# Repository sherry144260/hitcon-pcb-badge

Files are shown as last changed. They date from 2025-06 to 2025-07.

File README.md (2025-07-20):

# HITCON PCB Badge

## Firmware Development

execute `fw/merge.py` to merge STM32CubeIDE generated `main.c` with user code in `main.cc` into `main.cc`.

### Choose your hardware

In STM32CubeIDE, go to **Project > Build Configurations > Set Active > V1.1 / V2.0 / V2.1** to switch between hardware versions.  
Also go to **Run > Run Configurations > C/C++ Application** and choose the correct Build Configuration
There are different firmware versions for each hardware revision.  
To identify your hardware version, check the back of your badge.
- V1.1 (2024 CMT Attendee)
- V2.0 (2025 first prototype)
- V2.1 (2025 CMT Attendee)

## Timers and DMA Channels

- [x] IR Tx: PWM Output from TIM3_CH3, Output PB0, DMA1 Ch2
  - Compare: 63/4 = 16
  - Mode: Circular Normal Peripheral to Memory

| | Peripheral | Memory |
| --- | --- | --- |
| Increment Address | X | V |
| Data Width | Half Word  | Half Word |

- [x] IR Rx: DMA Triggered through TIM2_CH3, Input PA0 read by DMA1 Ch1
  - Compare: 105
  - Mode: Circular Peripheral to Memory

| | Peripheral | Memory |
| --- | --- | --- |
| Increment Address | X | V |
| Data Width | Half Word  | Half Word |

- [x] Led Rows/Cols: DMA Triggered through TIM1_UP, Output PB6-9(Rows), Output PB1-2/10-15(Cols), written by DMA1 Ch5
  - Mode: Circular Memory to Peripheral

| | Peripheral | Memory |
| --- | --- | --- |
| Increment Address | X | V |
| Data Width | Word | Word |

- [x] Led Brightness control: PWM Output from TIM3_CH2
- [x] Buttons: Reads Input PA4-10, PA15 through TIM4_CH2, DMA1 Ch4
  - Compare: 5
  - Mode: Circular Peripheral to Memory

| | Peripheral | Memory |
| --- | --- | --- |
| Increment Address | X | V |
| Data Width | Half Word  | Half Word |

- [x] Cross-board communication TX: USART2 TX, DMA1 Ch7
- [x] Cross-board communication RX: USART2 RX, DMA1 Ch6

- [x] TIM4: Operates at 100Hz for Button
  - Prescaler: 12000-1
  - Counter Period: 10-1
- [x] TIM3: Operates at 38kHz for PWM out.
  - Prescaler: 5-1
  - Counter Period: 63-1
  - Master Mode Enable
- [x] TIM2:
  - Prescaler: 0
  - Counter Period: 4-1
  - Slave Mode: External Clock
  - Trigger Source: ITR2 (TIM3 Update Event)
  - Operates at 1/4 speed of TIM3, synchronization needed for IR pulse alignment and brightness adjustment.
  - Also operates at 1/4 bit time for capturing IR.
  - TIM2 = 38/4 kHz = 9.5kHz.
  - Bit time = 4/9.5kHz = 421us (each bit is 16 pulse).
- [x] TIM1:
  - Prescaler: 5-1
  - Counter Period: 1500-1
  - LED refreshes at 3200/16 = 200Hz.

## Format

To check format, please install `clang-format` first.

```sh
# under hitcon-pcb-badge
./lint.sh # check format
./lint.sh -i # auto format
```

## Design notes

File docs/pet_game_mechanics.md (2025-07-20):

# 設備條件
畫面 8x16 
LED燈藍色和紅色，一台只有一種顏色

# 遊戲機制

- 第一次進入遊戲，可以選擇要孵狗蛋還是貓蛋
- 選擇後開始計搖晃次數，顯示孵蛋進度條（計次300下後孵蛋成功）
    - Global 晃動次數。
- 若孵蛋成功，再次進入遊戲畫面時即可看到你的寵物
    - Optional: 孵蛋成功小動畫（Justin 要畫嗎)
        > Yee (ok)
- 寵物有「生命值」、「等級」、「飽食度」三個數值
    - 生命值：三顆心，生命值歸零寵物進入虛弱狀態
        - aka, 能輸幾次
    - 飽食度：全滿為4，每1小時扣1飽食度，若飽食度歸零寵物進入虛弱畫面
    - 等級：初始為1，每計次100下等級+1 **(越來越難，算式待訂)**
-  可做行動
    - 訓練：NBA Shot meter練習器，若5次全中增加1等
        - 進度條 QTE
    - 餵食：可愛動畫，增加一格飽實度，畫面顯示你是一個好駭客
    - 戰鬥
        - 雙方進入戰鬥畫面，對接後顯示「Are you ready?」 任何一方按確認後進入戰鬥畫面
            > too many words, changed to icon - Yee (ok)
        - 戰鬥方式：NBA shot meter (Aoaa 看得懂)
            - 對戰方式：
                - Hitbox 每次隨機出現，下方指示物會來回走一次，玩家需要在下方指示物對準Hitbox時按下確認鍵，才算成功。
                - 指示物來回走一次以後會改變hitbox位子
                - 此過程進行5次後計分
            - 對戰後計算
                - 攻擊力(等級) X 成功次數的平方，兩個數字比大小，贏者勝 
                    - 一局比大小結束
                - 若成功次數為5次，有1%機率引發直接讓對方進入虛弱狀態的爆擊
                - 贏的一方補一顆心，輸的一方減少一顆心
- 小駭客中心(寶可夢中心)：Badge與寶可夢中心對接，補滿三顆心和飽食度
- 若寵物進入虛弱狀態，降一等，並無法進行任何活動，需要到寶可夢中心回滿血後才可繼續遊戲

# 遊戲功能階層

(孵蛋前)
- 小駭客
    - 畫面顯示選擇狗狗 OR 貓貓，選擇後進入孵蛋進度條

(孵蛋後)
- 小駭客
    - 寵物畫面（希望可以是動畫）
        - 狀態顯示
            - 血條
            - 等級/等級條
            - 飽實度
        - 訓練
        - 餵食
        - 戰鬥

# 畫面需求 for Justin
1. 蛋
2. 孵蛋成功小動畫
3. 狗&貓 (8x16的版面都可以用，希望可以動)
4. 貓虛弱畫面/狗虛弱畫面
5. 寶可夢中心 (愛心跑馬燈之類的)

---

### 跨版對戰相關

> 註：畫面不用額外刻

1. tama APP pet idle 狀態下，偵測板子是否對插 
    * 參考畫面 截圖 2025-07-06 下午6.23.48
2. 確認對插，跳出戰鬥確認頁面 
    * 截圖 2025-07-06 下午6.24.52

3. 雙方確認戰鬥，==交換寵物種類==。(按退出則回 tama app pet idle) 
4. 進入戰鬥對峙互看頁面
    * 截圖 2025-07-06 下午6.25.25
5. 畫面 delay 幾秒後跳出 "Battle start" page
6. "Battle start" page 過幾秒內進入 QTE game page
7. 進行五次 QTE，統計成功次數(需計時 timeout)
8. 完成QTE的，等待

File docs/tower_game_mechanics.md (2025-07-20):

# 設備數量
15-20個基地台
基地台和Badge可雙向溝通
基地台可傳輸距離約5-10公尺

# 遊戲機制

## 遊戲機制簡介
1. 一開始所有都是中立塔台，中立塔台需要分數達到一定程度才會被佔領
    - 塔台數值：設定分數下限 & 上限，中間有一區間會判定為中立塔台。EX: -1000 ~ 1000, 中間-300~300為中立值
3. 會眾透過遊戲、互動取得分數，分數會立即被使用到攻擊／防禦附近的塔台 
4. 塔台數值會隨時間下降，因此已經被佔領的塔台，若有一段時間都沒有人去加減分數，會回到中立塔台
5. 佔領塔數較多的該隊獲勝

待確認：
1. 有鑽漏洞（讓會眾玩Hacking）的機制嗎
2. 可以當內鬼?

## 分數類別 & 分數使用機制

### 分數類別
~~- 可使用分數：玩任一遊戲，還可以支配的分數~~
- 已使用分數

### 分數使用機制 

#### 獲得當下立刻使用
* 人潮明顯，好拍照，但會怕把議程空間擠爆
* 不需要額外有一個數值儲存已取得的分數

## 取得分數的方法
注意：這邊所有的分數定義都是先以會眾角度為考量，因此先不考慮藍隊實際上是+10/ 紅隊實際上計分是-10這個問題
* 站在塔台旁邊搖晃Badge
    * 一般塔台
        *  10秒內搖晃次數超過20次 +10分
            * 設定原因：希望是有意識的搖晃再計分，不要單純走路就計分
        * 每5秒多+1分
        * EX 連續搖晃20秒時，會變成10+11分。搖晃30秒時，會變成10+11+12。搖晃越久分數增加越多
    * 贊助商塔台
        * 10秒內搖晃次數超過20次 +20分
        * 每5秒多+2分
        * EX 連續搖晃20秒時，會變成20+21分。
* 小遊戲：
    * Dino
        * 每5秒計2分
        * 每5秒多+1分
        * EX: 成功跑15秒，分數為2+3+4
    * Snake
        + Snake score 每5分計1分
        + 每5分多+1分
        + 單機模式，EX: 若Snake score結果顯示為35，分數為= 1+2+3+4+5+6+7
        + 對戰模式：勝利的一方獲得2倍的分數，輸的一方獲得一倍的分數
        (給石頭：分數後端算。勝利與否只看分數高低。即便貪食蛇有人先撞牆，還是分數高的贏。若平分的話就是送一樣的分數)
    * Tetris
        * Tetris Score 每15分計1分
        * 每15分多+1分
        * 單機模式，EX: 若Tetris score結果顯示為150，1+2+3+4+5+6+7+8+9+10
        * 對戰模式：勝利的一方獲得2倍的分數，輸的一方獲得一倍的分數
        (給石頭：分數後端算。勝利與否只看分數高低。即便貪食蛇有人先撞牆輸了。若平分的話就是送一樣的分數)
* 贊助商活動
    * 贊助商放特殊基地台，在贊助商旁邊搖晃Badge的話可獲得更多分數
        * 10秒內搖晃次數超過20次 +20分
        * 每5秒多+2分
        * EX 連續搖晃20秒時，會變成20+21分。
    * 贊助商有特殊Badge 
        * 跟贊助商對接Badge，駭客寵物可升一等，一個贊助商只能讓寵物升等一次 (重複對接不能重複升等)
        * 若跟所有贊助商都對接過一次，隨即攻擊/防禦附近的塔台300分
       
* ReCTF：解題可以獲得分數倍率
    * 預設題目有24題
    * CTFd 登入 官網 SSO Token 後，可以在 Profile 頁面綁定 Badge。(活動前edward會事先提供一個解多少題的清單)
    * 每解一題可以增加0.04的分數倍率，EX: 倍率為1.04、1.08、1.12、1.16.....，全部解完的分數倍率為兩倍(先成上去後小數點四捨五入)

## 遊戲結算
* 團隊：佔領塔數較多的那隊獲勝（獎品待確認）
* 個人：已使用分數最高者獲勝

設定獲勝條件

## 記分板
* 個人已經輸出過的分數
* 地圖：各地佔領情況，分數差異

archieve
胎死腹中的想法
~~有沒有台主~~

分數儲存後使用 (建議)
說明：獲得分數後儲存起來，之後再決定要將分數加到哪個塔台
* 人流不會都擠在基地台旁邊（畢竟基地台可能會放在議程空間裡面）
* 在何時何地都可以參與遊戲，可以回家繼續玩小遊戲累積分數

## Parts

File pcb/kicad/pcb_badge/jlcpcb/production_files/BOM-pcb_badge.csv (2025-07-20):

Comment | Designator | Footprint | LCSC
0.1u | C1,C21,C30,C31,C32,C33,C40,C50,C51,C80 | C_0402_1005Metric_Pad0.74x0.62mm_HandSolder | C1525
1u | C10,C11 | C_0603_1608Metric_Pad1.08x0.95mm_HandSolder | C152900
20p | C37,C38 | C_0402_1005Metric_Pad0.74x0.62mm_HandSolder | C1554
4.7u | C60 | C_0603_1608Metric_Pad1.08x0.95mm_HandSolder | C1705
10M | R11,R4 | R_0402_1005Metric_Pad0.72x0.64mm_HandSolder | C177265
TLV70328DBVR | U1 | SOT-23-5 | C19631758
10u | C20,C22,C23,C24,C25,C26,C92 | C_0603_1608Metric_Pad1.08x0.95mm_HandSolder | C19702
20R | R1,R2 | R_0402_1005Metric_Pad0.72x0.64mm_HandSolder | C203133
QX2304L33F | U2 | SOT-23-5 | C219039
100 | R61 | R_0402_1005Metric_Pad0.72x0.64mm_HandSolder | C25076
220 | R14 | R_0402_1005Metric_Pad0.72x0.64mm_HandSolder | C25091
300 | R90,R91,R92,R93,R94,R95,R96,R97 | R_0402_1005Metric_Pad0.72x0.64mm_HandSolder | C25102
470 | R21,R31,R32,R33,R34,R8,R9 | R_0402_1005Metric_Pad0.72x0.64mm_HandSolder | C25117
SW_MEC_5E | SW1,SW2,SW3,SW4,SW5,SW6,SW7,SW8 | SOIC4_TL3301SPF160RGTAPE_EWI | C255812
100k | R16,R17,R18,R19,R5,R6,R7 | R_0402_1005Metric_Pad0.72x0.64mm_HandSolder | C25741
4.7k | R20,R3,R50,R51 | R_0402_1005Metric_Pad0.72x0.64mm_HandSolder | C25900
5.1k | R24,R25 | R_0402_1005Metric_Pad0.72x0.64mm_HandSolder | C25905
CYL104R-33UH | L20 | L_10.4x10.4_H4.8 | C2879699
Conn_01x03_Pin | J5 | PinHeader_1x03_P2.54mm_Vertical | C2897385
DEALON USB-TYPE-C-018 | J1 | DEALON USB-TYPE-C-018 | C2927038
110R | R164 | R_1206_3216Metric_Pad1.30x1.75mm_HandSolder | C2934192
SOD4007-MS | D18,D2 | D_SOD-123F | C3008061
TAXM8M4RFDCET2T | Y1 | Oscillator_SMD_Abracon_ASE-4Pin_3.2x2.5mm | C403948
SI2302 | Q1 | SOT-23 | C4748714
2N7002 | Q9,Q90,Q91,Q910,Q911,Q912,Q913,Q914,Q915,Q92,Q93,Q94,Q95,Q96,Q97,Q98,Q99 | SOT-23 | C4748728
NSR0320MW2T1G | D9 | D_SOD-323_HandSoldering | C48192
Conn_01x03_Pin | J4 | PinHeader_1x03_P2.54mm_Vertical | C5383096
0 | R10,R23 | R_0402_1005Metric_Pad0.72x0.64mm_HandSolder | C60485
NEWOPTO XYC-IRA2835A90-X4 | D161 | LED_PLCC_2835_Handsoldering | C6081290
74HC238 | U4,U8 | SOP-16_3.9x9.9mm_P1.27mm | C7432189
STM32F103CBT6 | U3 | LQFP-48_7x7mm_P0.5mm | C8304
IRM-H638T/TR2 | U6 | IRM-H638T | C91447
JSM2301S | Q2 | SOT-23 | C916399
BAT_2 | BT1 | BH-AAA-B5AK001 | C964881
LED | D00,D01,D02,D03,D04,D05,D06,D07,D10,D100,D101,D102,D103,D104,D105,D106,D107,D11,D110,D111,D112,D113,D114,D115,D116,D117,D12,D120,D121,D122,D123,D124,D125,D126,D127,D13,D130,D131,D132,D133,D134,D135,D136,D137,D14,D140,D141,D142,D143,D144,D145,D146,D147,D15,D150,D151,D152,D153,D154,D155,D156,D157,D16,D17,D20,D21,D22,D23,D24,D25,D26,D27,D30,D31,D32,D33,D34,D35,D36,D37,D40,D41,D42,D43,D44,D45,D46,D47,D50,D51,D52,D53,D54,D55,D56,D57,D60,D61,D62,D63,D64,D65,D66,D67,D70,D71,D72,D73,D74,D75,D76,D77,D80,D81,D82,D83,D84,D85,D86,D87,D90,D91,D92,D93,D94,D95,D96,D97 | LED_0402_1005Metric_Pad0.77x0.64mm_HandSolder | C965790
LSM6DS3TR-C | U5 | QFN_S3TR-C_STM | C967633
NC | D160 | LED_PLCC_2835_Handsoldering
Conn_01x02_Pin | J7 | PinHeader_1x02_P2.54mm_Vertical
NC | D3 | LED_0603_1608Metric_Pad1.05x0.95mm_HandSolder
Conn_01x04_Pin | J3 | PinHeader_1x04_P2.54mm_Vertical
NC | R29 | R_0402_1005Metric_Pad0.72x0.64mm_HandSolder
NC | R36 | R_0402_1005Metric_Pad0.72x0.64mm_HandSolder
NC | R35 | R_0402_1005Metric_Pad0.72x0.64mm_HandSolder
NC | C34 | C_0402_1005Metric_Pad0.74x0.62mm_HandSolder
NC | R22 | R_0402_1005Metric_Pad0.72x0.64mm_HandSolder
NC | D1 | D_SOD-323_HandSoldering
NC | R30 | R_0402_1005Metric_Pad0.72x0.64mm_HandSolder
NC | D164 | LED_PLCC_2835_Handsoldering
NC | D166 | LED_PLCC_2835_Handsoldering
Conn_01x02_Pin | J2 | JWT_A3963_1x02_P3.96mm_Vertical
NC | D163 | LED_PLCC_2835_Handsoldering
NC | D167 | LED_PLCC_2835_Handsoldering
NC | D162 | LED_PLCC_2835_Handsoldering
NC | D165 | LED_PLCC_2835_Handsoldering
NC | R165 | R_1206_3216Metric_Pad1.30x1.75mm_HandSolder
NC | R166 | R_1206_3216Metric_Pad1.30x1.75mm_HandSolder
NC | R162 | R_1206_3216Metric_Pad1.30x1.75mm_HandSolder
NC | R167 | R_1206_3216Metric_Pad1.30x1.75mm_HandSolder
NC | R163 | R_1206_3216Metric_Pad1.30x1.75mm_HandSolder

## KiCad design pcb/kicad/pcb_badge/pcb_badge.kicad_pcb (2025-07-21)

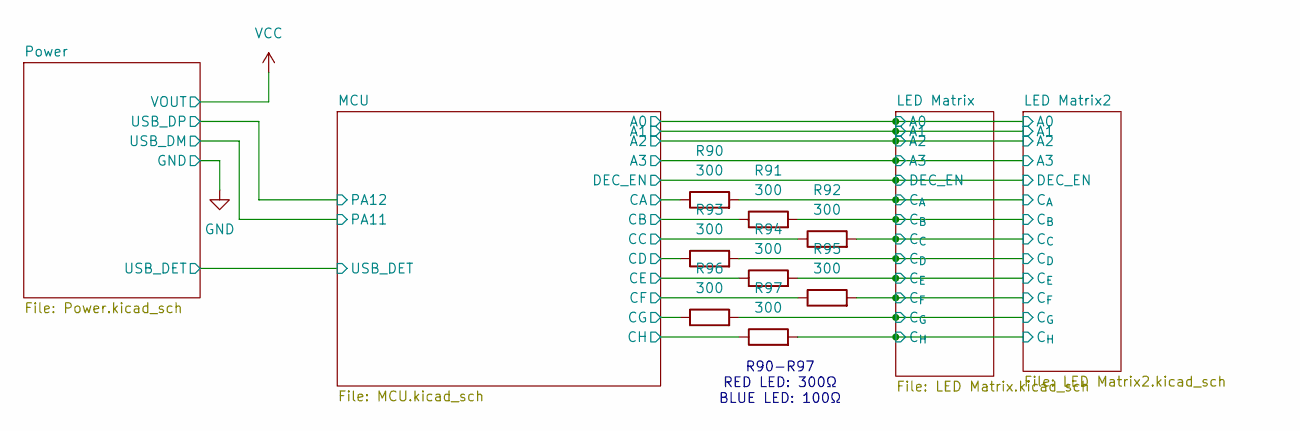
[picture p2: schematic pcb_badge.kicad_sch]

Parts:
R90, R91, R92, R93, R94, R95, R96, R97: 300; R_0402_1005Metric_Pad0.72x0.64mm_HandSolder

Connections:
/LED Matrix/MAT_CA: R90.2; also elsewhere on the board
/LED Matrix/MAT_CB: R91.2; also elsewhere on the board
/LED Matrix/MAT_CC: R92.2; also elsewhere on the board
/LED Matrix/MAT_CD: R93.2; also elsewhere on the board
/LED Matrix/MAT_CE: R94.2; also elsewhere on the board
/LED Matrix/MAT_CF: R95.2; also elsewhere on the board
/LED Matrix/MAT_CG: R96.2; also elsewhere on the board
/LED Matrix/MAT_CH: R97.2; also elsewhere on the board
/MCU/CA: R90.1; also elsewhere on the board
/MCU/CB: R91.1; also elsewhere on the board
/MCU/CC: R92.1; also elsewhere on the board
/MCU/CD: R93.1; also elsewhere on the board
/MCU/CE: R94.1; also elsewhere on the board
/MCU/CF: R95.1; also elsewhere on the board
/MCU/CG: R96.1; also elsewhere on the board
/MCU/CH: R97.1; also elsewhere on the board

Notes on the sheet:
R90-R97 RED LED: 300Ω BLUE LED: 100Ω

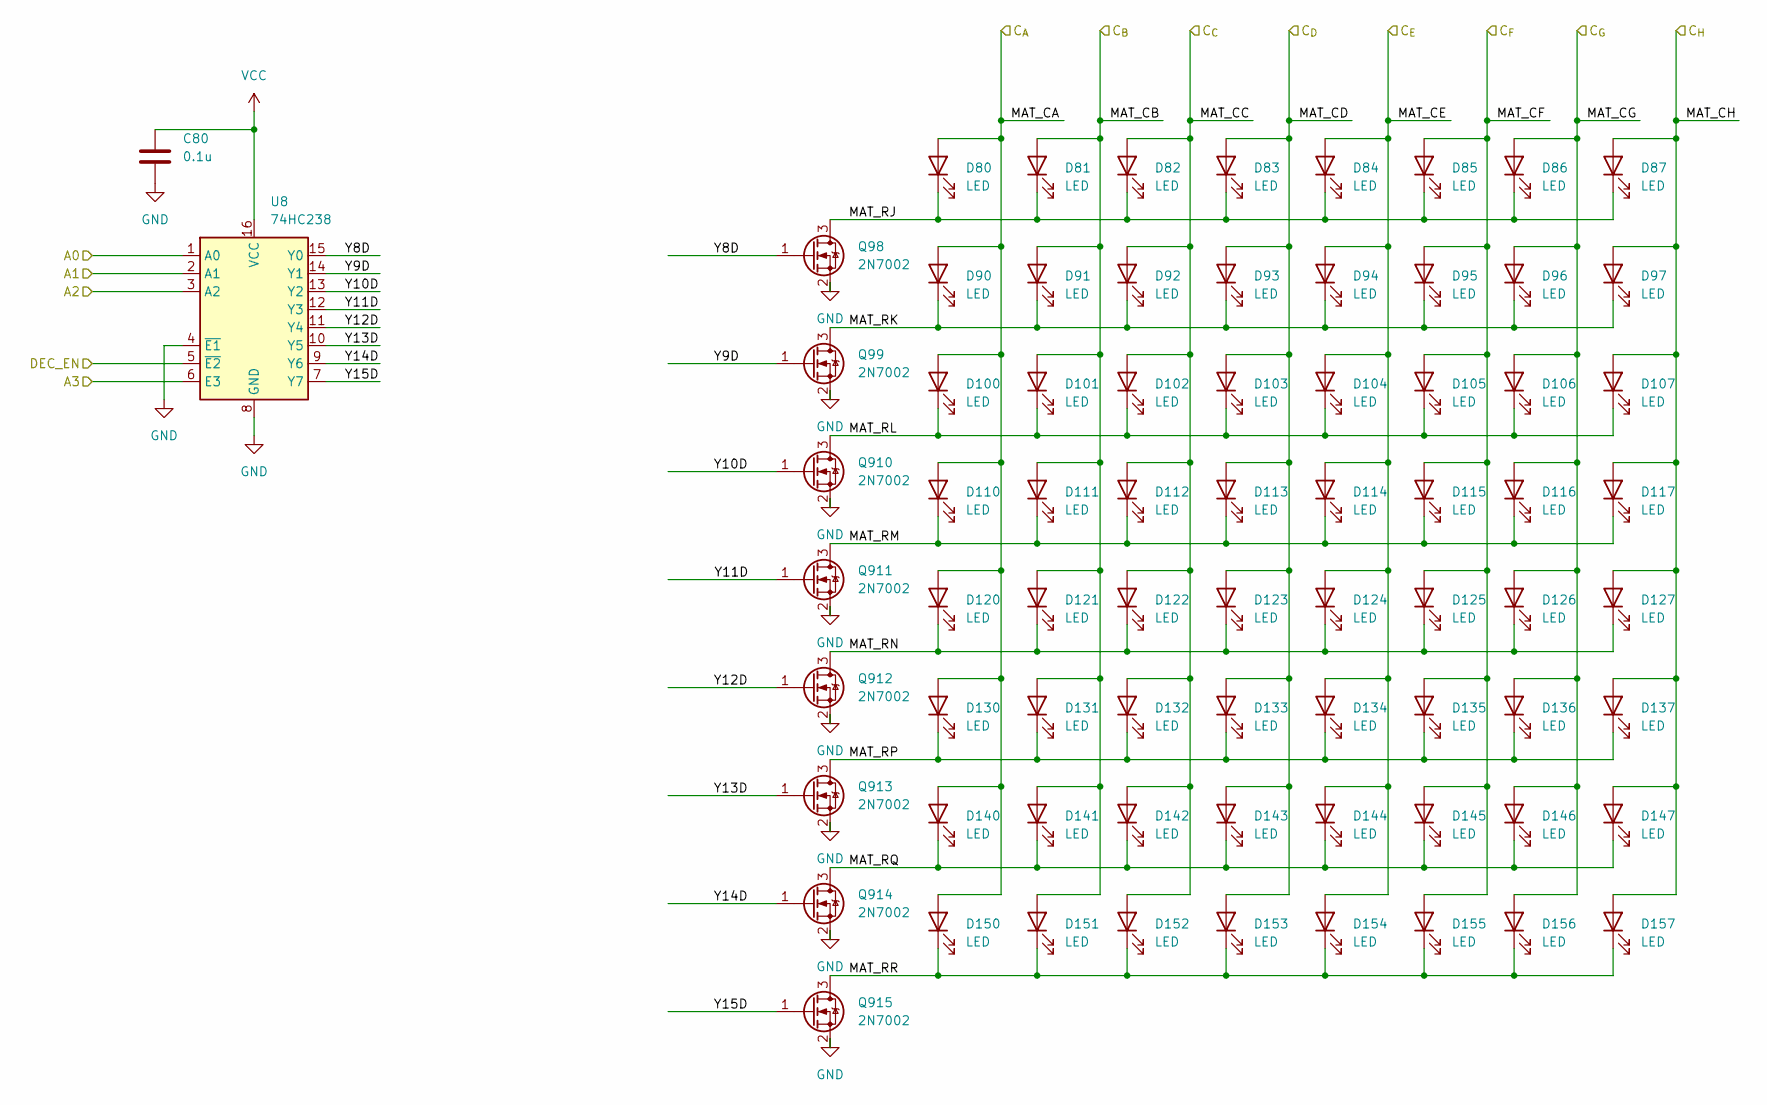
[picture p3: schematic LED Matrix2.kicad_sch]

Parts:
C80: 0.1u; C_0402_1005Metric_Pad0.74x0.62mm_HandSolder
D80, D81, D82, D83, D84, D85, D86, D87, D90, D91, D92, D93, D94, D95, D96, D97, D100, D101, D102, D103, D104, D105, D106, D107, D110, D111, D112, D113, D114, D115, D116, D117, D120, D121, D122, D123, D124, D125, D126, D127, D130, D131, D132, D133, D134, D135, D136, D137, D140, D141, D142, D143, D144, D145, D146, D147, D150, D151, D152, D153, D154, D155, D156, D157: LED; LED_0402_1005Metric_Pad0.77x0.64mm_HandSolder
Q98, Q99, Q910, Q911, Q912, Q913, Q914, Q915: 2N7002; SOT-23
U8: 74HC238; SOP-16_3.9x9.9mm_P1.27mm

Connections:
/LED Matrix2/MAT_RJ: D80.1 (K), D81.1 (K), D82.1 (K), D83.1 (K), D84.1 (K), D85.1 (K), D86.1 (K), D87.1 (K), Q98.3 (D)
/LED Matrix2/MAT_RK: D90.1 (K), D91.1 (K), D92.1 (K), D93.1 (K), D94.1 (K), D95.1 (K), D96.1 (K), D97.1 (K), Q99.3 (D)
/LED Matrix2/MAT_RL: D100.1 (K), D101.1 (K), D102.1 (K), D103.1 (K), D104.1 (K), D105.1 (K), D106.1 (K), D107.1 (K), Q910.3 (D)
/LED Matrix2/MAT_RM: D110.1 (K), D111.1 (K), D112.1 (K), D113.1 (K), D114.1 (K), D115.1 (K), D116.1 (K), D117.1 (K), Q911.3 (D)
/LED Matrix2/MAT_RN: D120.1 (K), D121.1 (K), D122.1 (K), D123.1 (K), D124.1 (K), D125.1 (K), D126.1 (K), D127.1 (K), Q912.3 (D)
/LED Matrix2/MAT_RP: D130.1 (K), D131.1 (K), D132.1 (K), D133.1 (K), D134.1 (K), D135.1 (K), D136.1 (K), D137.1 (K), Q913.3 (D)
/LED Matrix2/MAT_RQ: D140.1 (K), D141.1 (K), D142.1 (K), D143.1 (K), D144.1 (K), D145.1 (K), D146.1 (K), D147.1 (K), Q914.3 (D)
/LED Matrix2/MAT_RR: D150.1 (K), D151.1 (K), D152.1 (K), D153.1 (K), D154.1 (K), D155.1 (K), D156.1 (K), D157.1 (K), Q915.3 (D)
/LED Matrix2/Y8D: Q98.1 (G), U8.15 (Y0)
/LED Matrix2/Y9D: Q99.1 (G), U8.14 (Y1)
/LED Matrix2/Y10D: Q910.1 (G), U8.13 (Y2)
/LED Matrix2/Y11D: Q911.1 (G), U8.12 (Y3)
/LED Matrix2/Y12D: Q912.1 (G), U8.11 (Y4)
/LED Matrix2/Y13D: Q913.1 (G), U8.10 (Y5)
/LED Matrix2/Y14D: Q914.1 (G), U8.9 (Y6)
/LED Matrix2/Y15D: Q915.1 (G), U8.7 (Y7)
/LED Matrix/A0: U8.1 (A0); also elsewhere on the board
/LED Matrix/A1: U8.2 (A1); also elsewhere on the board
/LED Matrix/A2: U8.3 (A2); also elsewhere on the board
/LED Matrix/A3: U8.6 (E3); also elsewhere on the board
/LED Matrix/DEC_EN: U8.5 (~E2); also elsewhere on the board
/LED Matrix/MAT_CA: D80.2 (A), D90.2 (A), D100.2 (A), D110.2 (A), D120.2 (A), D130.2 (A), D140.2 (A), D150.2 (A); also elsewhere on the board
/LED Matrix/MAT_CB: D81.2 (A), D91.2 (A), D101.2 (A), D111.2 (A), D121.2 (A), D131.2 (A), D141.2 (A), D151.2 (A); also elsewhere on the board
/LED Matrix/MAT_CC: D82.2 (A), D92.2 (A), D102.2 (A), D112.2 (A), D122.2 (A), D132.2 (A), D142.2 (A), D152.2 (A); also elsewhere on the board
/LED Matrix/MAT_CD: D83.2 (A), D93.2 (A), D103.2 (A), D113.2 (A), D123.2 (A), D133.2 (A), D143.2 (A), D153.2 (A); also elsewhere on the board
/LED Matrix/MAT_CE: D84.2 (A), D94.2 (A), D104.2 (A), D114.2 (A), D124.2 (A), D134.2 (A), D144.2 (A), D154.2 (A); also elsewhere on the board
/LED Matrix/MAT_CF: D85.2 (A), D95.2 (A), D105.2 (A), D115.2 (A), D125.2 (A), D135.2 (A), D145.2 (A), D155.2 (A); also elsewhere on the board
/LED Matrix/MAT_CG: D86.2 (A), D96.2 (A), D106.2 (A), D116.2 (A), D126.2 (A), D136.2 (A), D146.2 (A), D156.2 (A); also elsewhere on the board
/LED Matrix/MAT_CH: D87.2 (A), D97.2 (A), D107.2 (A), D117.2 (A), D127.2 (A), D137.2 (A), D147.2 (A), D157.2 (A); also elsewhere on the board
GND: C80.2, Q98.2 (S), Q99.2 (S), Q910.2 (S), Q911.2 (S), Q912.2 (S), Q913.2 (S), Q914.2 (S), Q915.2 (S), U8.4 (~E1), U8.8 (GND); also elsewhere on the board
VCC: C80.1, U8.16 (VCC); also elsewhere on the board

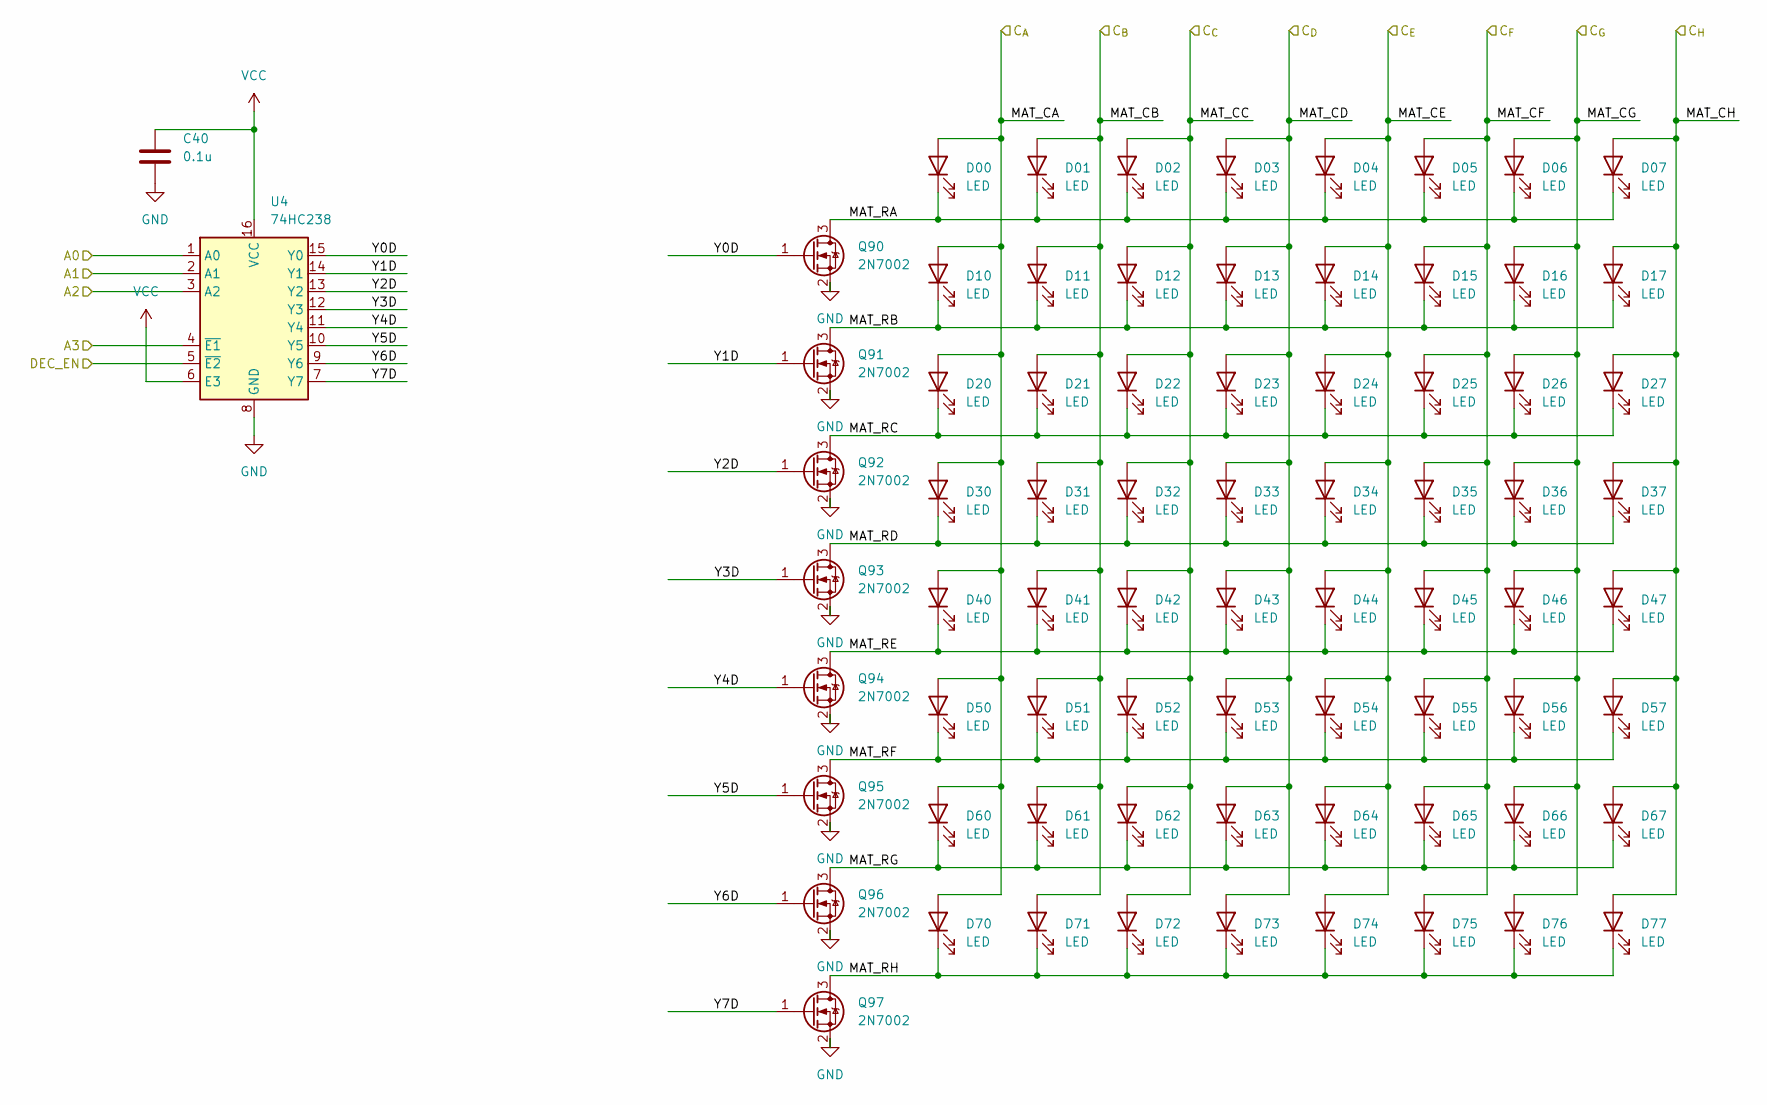
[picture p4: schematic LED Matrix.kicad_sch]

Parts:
C40: 0.1u; C_0402_1005Metric_Pad0.74x0.62mm_HandSolder
D00, D01, D02, D03, D04, D05, D06, D07, D10, D11, D12, D13, D14, D15, D16, D17, D20, D21, D22, D23, D24, D25, D26, D27, D30, D31, D32, D33, D34, D35, D36, D37, D40, D41, D42, D43, D44, D45, D46, D47, D50, D51, D52, D53, D54, D55, D56, D57, D60, D61, D62, D63, D64, D65, D66, D67, D70, D71, D72, D73, D74, D75, D76, D77: LED; LED_0402_1005Metric_Pad0.77x0.64mm_HandSolder
Q90, Q91, Q92, Q93, Q94, Q95, Q96, Q97: 2N7002; SOT-23
U4: 74HC238; SOP-16_3.9x9.9mm_P1.27mm

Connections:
/LED Matrix/A0: U4.1 (A0); also elsewhere on the board
/LED Matrix/A1: U4.2 (A1); also elsewhere on the board
/LED Matrix/A2: U4.3 (A2); also elsewhere on the board
/LED Matrix/A3: U4.4 (~E1); also elsewhere on the board
/LED Matrix/DEC_EN: U4.5 (~E2); also elsewhere on the board
/LED Matrix/MAT_CA: D00.2 (A), D10.2 (A), D20.2 (A), D30.2 (A), D40.2 (A), D50.2 (A), D60.2 (A), D70.2 (A); also elsewhere on the board
/LED Matrix/MAT_CB: D01.2 (A), D11.2 (A), D21.2 (A), D31.2 (A), D41.2 (A), D51.2 (A), D61.2 (A), D71.2 (A); also elsewhere on the board
/LED Matrix/MAT_CC: D02.2 (A), D12.2 (A), D22.2 (A), D32.2 (A), D42.2 (A), D52.2 (A), D62.2 (A), D72.2 (A); also elsewhere on the board
/LED Matrix/MAT_CD: D03.2 (A), D13.2 (A), D23.2 (A), D33.2 (A), D43.2 (A), D53.2 (A), D63.2 (A), D73.2 (A); also elsewhere on the board
/LED Matrix/MAT_CE: D04.2 (A), D14.2 (A), D24.2 (A), D34.2 (A), D44.2 (A), D54.2 (A), D64.2 (A), D74.2 (A); also elsewhere on the board
/LED Matrix/MAT_CF: D05.2 (A), D15.2 (A), D25.2 (A), D35.2 (A), D45.2 (A), D55.2 (A), D65.2 (A), D75.2 (A); also elsewhere on the board
/LED Matrix/MAT_CG: D06.2 (A), D16.2 (A), D26.2 (A), D36.2 (A), D46.2 (A), D56.2 (A), D66.2 (A), D76.2 (A); also elsewhere on the board
/LED Matrix/MAT_CH: D07.2 (A), D17.2 (A), D27.2 (A), D37.2 (A), D47.2 (A), D57.2 (A), D67.2 (A), D77.2 (A); also elsewhere on the board
/LED Matrix/MAT_RA: D00.1 (K), D01.1 (K), D02.1 (K), D03.1 (K), D04.1 (K), D05.1 (K), D06.1 (K), D07.1 (K), Q90.3 (D)
/LED Matrix/MAT_RB: D10.1 (K), D11.1 (K), D12.1 (K), D13.1 (K), D14.1 (K), D15.1 (K), D16.1 (K), D17.1 (K), Q91.3 (D)
/LED Matrix/MAT_RC: D20.1 (K), D21.1 (K), D22.1 (K), D23.1 (K), D24.1 (K), D25.1 (K), D26.1 (K), D27.1 (K), Q92.3 (D)
/LED Matrix/MAT_RD: D30.1 (K), D31.1 (K), D32.1 (K), D33.1 (K), D34.1 (K), D35.1 (K), D36.1 (K), D37.1 (K), Q93.3 (D)
/LED Matrix/MAT_RE: D40.1 (K), D41.1 (K), D42.1 (K), D43.1 (K), D44.1 (K), D45.1 (K), D46.1 (K), D47.1 (K), Q94.3 (D)
/LED Matrix/MAT_RF: D50.1 (K), D51.1 (K), D52.1 (K), D53.1 (K), D54.1 (K), D55.1 (K), D56.1 (K), D57.1 (K), Q95.3 (D)
/LED Matrix/MAT_RG: D60.1 (K), D61.1 (K), D62.1 (K), D63.1 (K), D64.1 (K), D65.1 (K), D66.1 (K), D67.1 (K), Q96.3 (D)
/LED Matrix/MAT_RH: D70.1 (K), D71.1 (K), D72.1 (K), D73.1 (K), D74.1 (K), D75.1 (K), D76.1 (K), D77.1 (K), Q97.3 (D)
/LED Matrix/Y0D: Q90.1 (G), U4.15 (Y0)
/LED Matrix/Y1D: Q91.1 (G), U4.14 (Y1)
/LED Matrix/Y2D: Q92.1 (G), U4.13 (Y2)
/LED Matrix/Y3D: Q93.1 (G), U4.12 (Y3)
/LED Matrix/Y4D: Q94.1 (G), U4.11 (Y4)
/LED Matrix/Y5D: Q95.1 (G), U4.10 (Y5)
/LED Matrix/Y6D: Q96.1 (G), U4.9 (Y6)
/LED Matrix/Y7D: Q97.1 (G), U4.7 (Y7)
GND: C40.2, Q90.2 (S), Q91.2 (S), Q92.2 (S), Q93.2 (S), Q94.2 (S), Q95.2 (S), Q96.2 (S), Q97.2 (S), U4.8 (GND); also elsewhere on the board
VCC: C40.1, U4.6 (E3), U4.16 (VCC); also elsewhere on the board

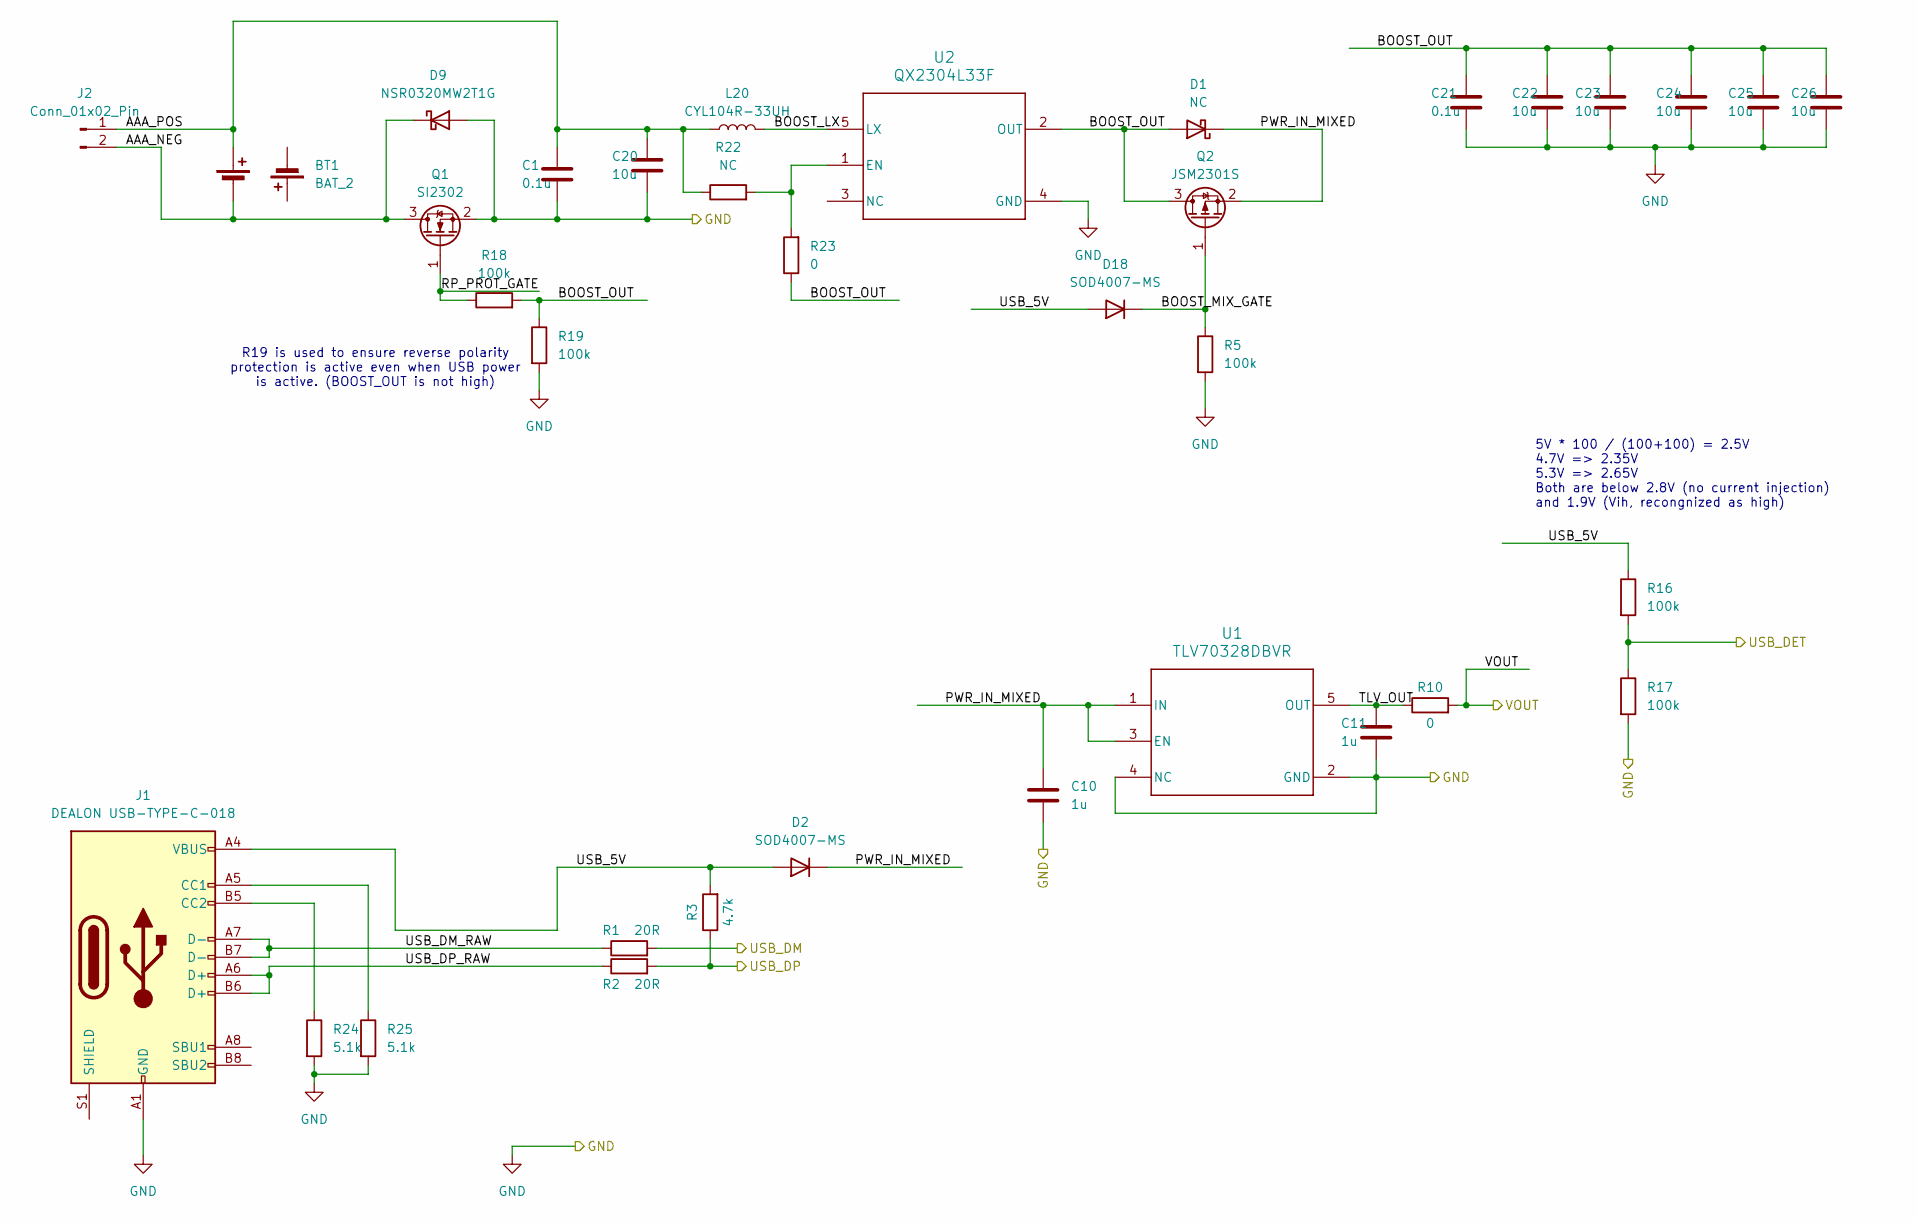
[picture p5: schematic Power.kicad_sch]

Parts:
BT1: BAT_2; BH-AAA-B5AK001
C1, C21: 0.1u; C_0402_1005Metric_Pad0.74x0.62mm_HandSolder
C10, C11: 1u; C_0603_1608Metric_Pad1.08x0.95mm_HandSolder
C20, C22, C23, C24, C25, C26: 10u; C_0603_1608Metric_Pad1.08x0.95mm_HandSolder
D1: NC; D_SOD-323_HandSoldering
D2, D18: SOD4007-MS; D_SOD-123F
D9: NSR0320MW2T1G; D_SOD-323_HandSoldering
J1: DEALON USB-TYPE-C-018
J2: Conn_01x02_Pin; JWT_A3963_1x02_P3.96mm_Vertical
L20: CYL104R-33UH; L_10.4x10.4_H4.8
Q1: SI2302; SOT-23
Q2: JSM2301S; SOT-23
R1, R2: 20R; R_0402_1005Metric_Pad0.72x0.64mm_HandSolder
R3: 4.7k; R_0402_1005Metric_Pad0.72x0.64mm_HandSolder
R5, R16, R17, R18, R19: 100k; R_0402_1005Metric_Pad0.72x0.64mm_HandSolder
R10, R23: 0; R_0402_1005Metric_Pad0.72x0.64mm_HandSolder
R22: NC; R_0402_1005Metric_Pad0.72x0.64mm_HandSolder
R24, R25: 5.1k; R_0402_1005Metric_Pad0.72x0.64mm_HandSolder
U1: TLV70328DBVR; SOT-23-5
U2: QX2304L33F; SOT-23-5

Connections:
/MCU/PA11: R1.2; also elsewhere on the board
/MCU/PA12: R2.2, R3.1; also elsewhere on the board
/MCU/USB_DET: R16.2, R17.1; also elsewhere on the board
/Power/AAA_NEG: BT1.2 (-), D9.1 (K), J2.2, Q1.3 (D)
/Power/AAA_POS: BT1.1 (+), C1.1, C20.1, J2.1, L20.1, R22.1
/Power/BOOST_LX: L20.2, U2.5 (LX)
/Power/BOOST_MIX_GATE: D18.1 (K), Q2.1 (G), R5.1
/Power/BOOST_OUT: C21.1, C22.1, C23.1, C24.1, C25.1, C26.1, D1.2 (A), Q2.3 (D), R18.2, R19.1, R23.1, U2.2 (OUT)
/Power/PWR_IN_MIXED: C10.2, D1.1 (K), D2.1 (K), Q2.2 (S), U1.1 (IN), U1.3 (EN)
/Power/RP_PROT_GATE: Q1.1 (G), R18.1
/Power/TLV_OUT: C11.1, R10.1, U1.5 (OUT)
/Power/USB_5V: D2.2 (A), D18.2 (A), J1.A4 (VBUS), J1.A9 (VBUS), J1.B4 (VBUS), J1.B9 (VBUS), R3.2, R16.1
/Power/USB_DM_RAW: J1.A7 (D-), J1.B7 (D-), R1.1
/Power/USB_DP_RAW: J1.A6 (D+), J1.B6 (D+), R2.1
GND: C1.2, C10.1, C11.2, C20.2, C21.2, C22.2, C23.2, C24.2, C25.2, C26.2, D9.2 (A), J1.A1 (GND), J1.A12 (GND), J1.B1 (GND), J1.B12 (GND), Q1.2 (S), R5.2, R17.2, R19.2, R24.2, R25.2, U1.2 (GND), U1.4 (NC), U2.4 (GND); also elsewhere on the board
unnamed: J1.A5 (CC1), R25.1
unnamed: J1.B5 (CC2), R24.1
unnamed: R22.2, R23.2, U2.1 (EN)
VCC: R10.2; also elsewhere on the board

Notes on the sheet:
R19 is used to ensure reverse polarity protection is active even when USB power is active. (BOOST_OUT is not high)
5V * 100 / (100+100) = 2.5V 4.7V => 2.35V 5.3V => 2.65V Both are below 2.8V (no current injection) and 1.9V (Vih, recongnized as high)

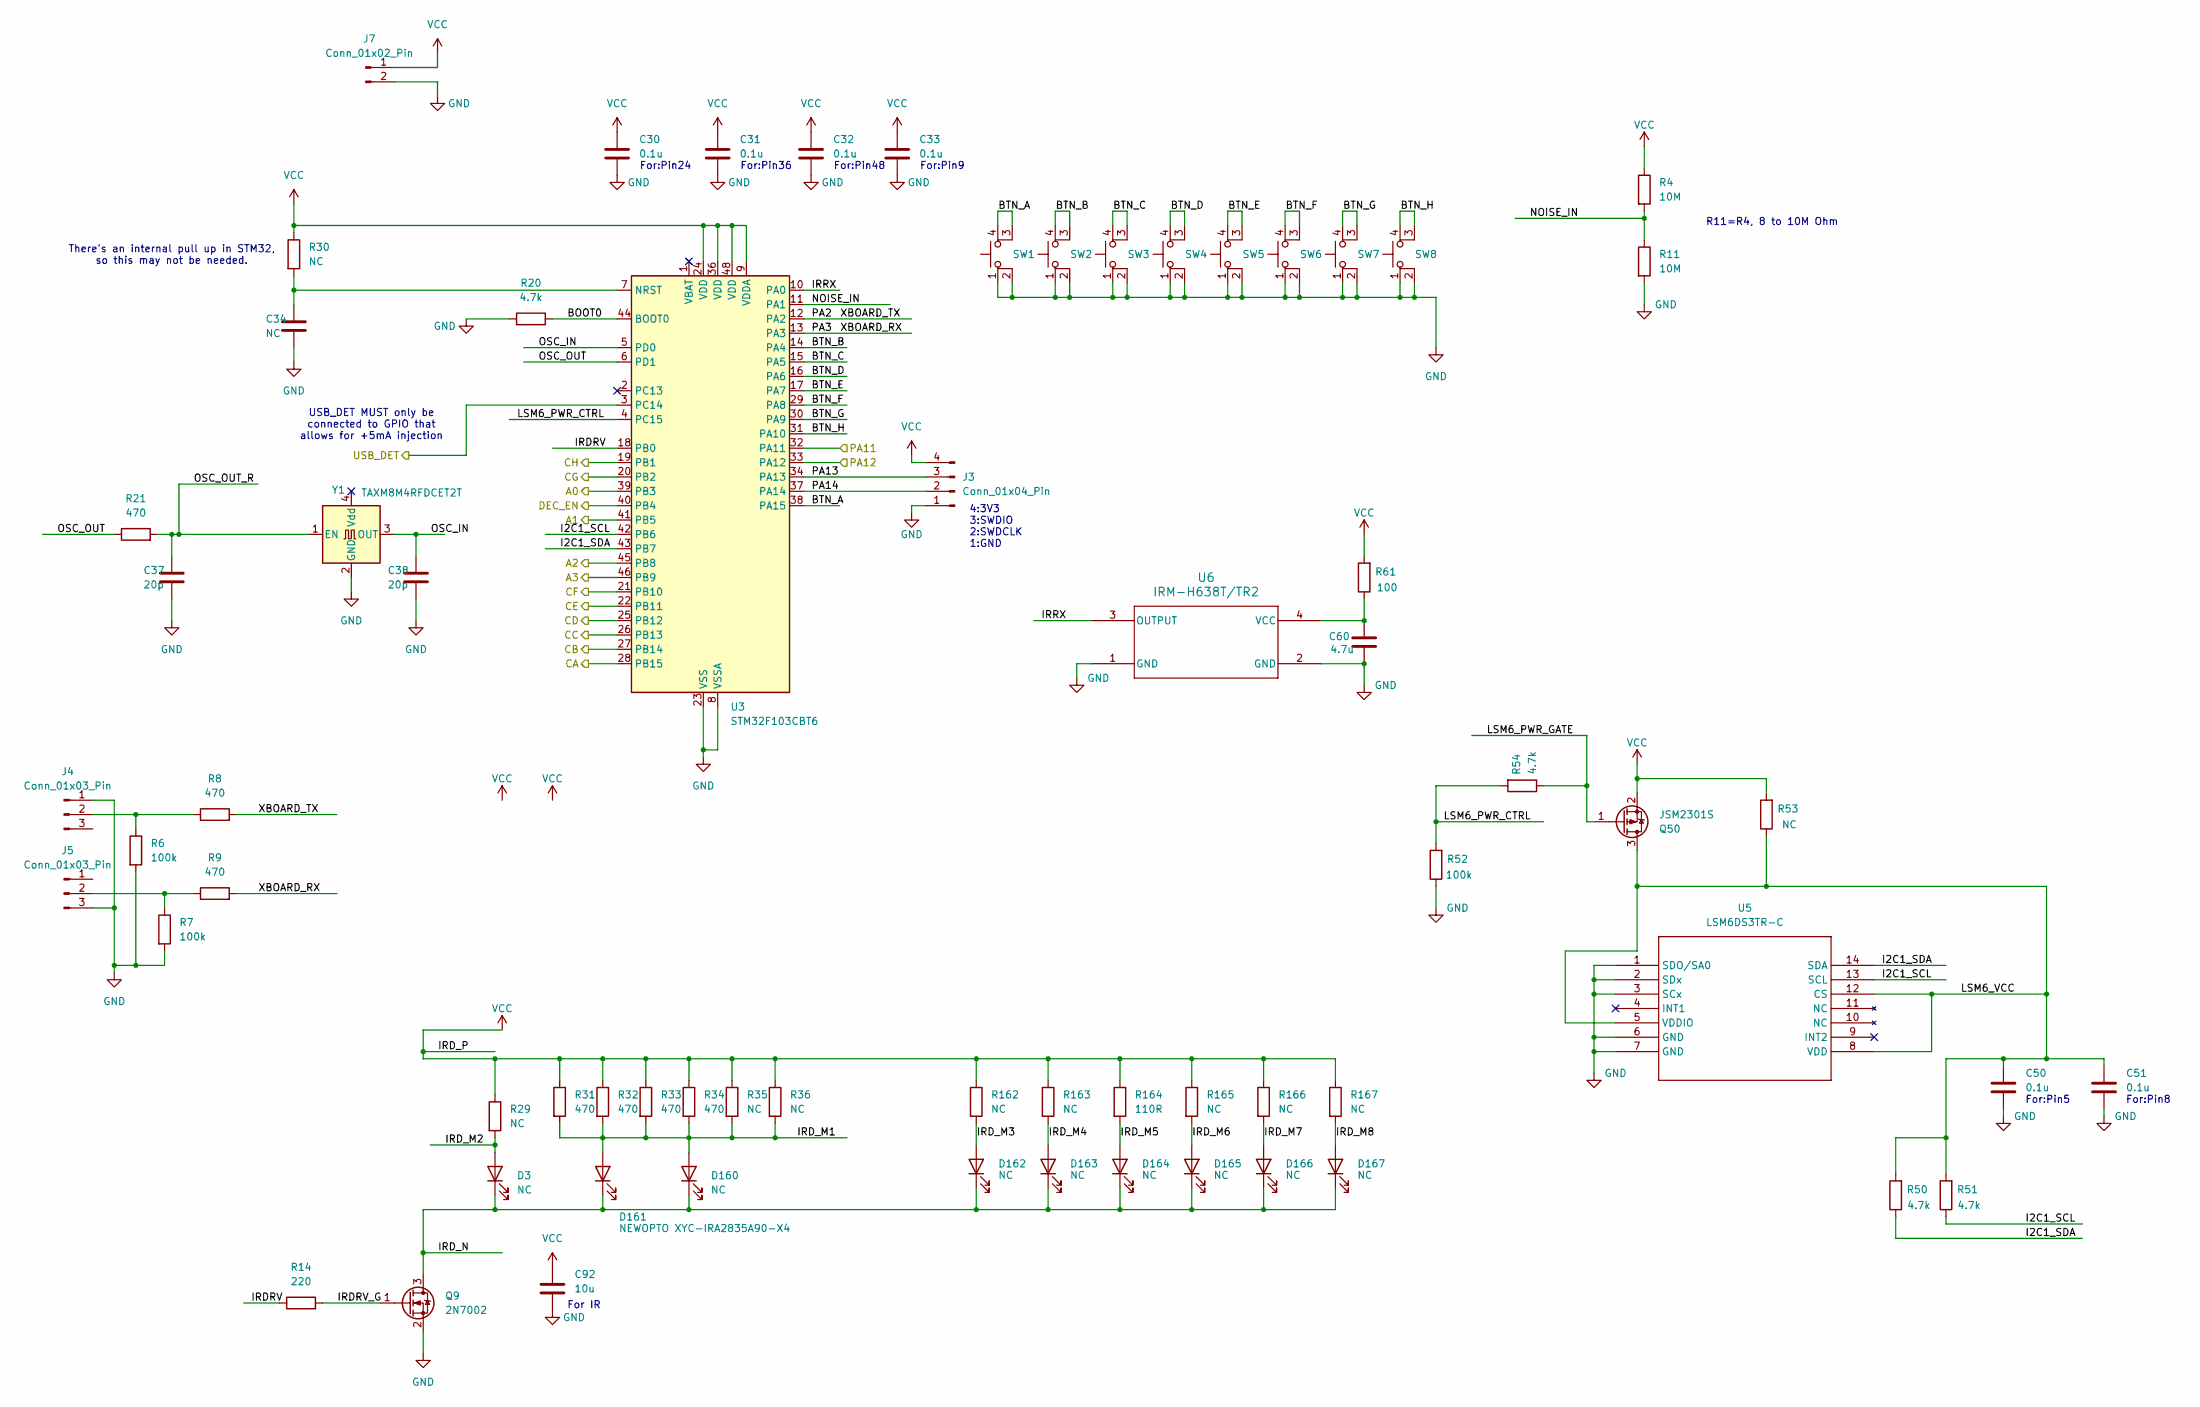
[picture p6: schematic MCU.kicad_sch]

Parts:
C30, C31, C32, C33, C50, C51: 0.1u; C_0402_1005Metric_Pad0.74x0.62mm_HandSolder
C34: NC; C_0402_1005Metric_Pad0.74x0.62mm_HandSolder
C37, C38: 20p; C_0402_1005Metric_Pad0.74x0.62mm_HandSolder
C60: 4.7u; C_0603_1608Metric_Pad1.08x0.95mm_HandSolder
C92: 10u; C_0603_1608Metric_Pad1.08x0.95mm_HandSolder
D3: NC; LED_0603_1608Metric_Pad1.05x0.95mm_HandSolder
D160, D162, D163, D164, D165, D166, D167: NC; LED_PLCC_2835_Handsoldering
D161: NEWOPTO XYC-IRA2835A90-X4; LED_PLCC_2835_Handsoldering
J3: Conn_01x04_Pin; PinHeader_1x04_P2.54mm_Vertical
J4, J5: Conn_01x03_Pin; PinHeader_1x03_P2.54mm_Vertical
J7: Conn_01x02_Pin; PinHeader_1x02_P2.54mm_Vertical
Q9: 2N7002; SOT-23
Q50: JSM2301S; SOT-23
R4, R11: 10M; R_0402_1005Metric_Pad0.72x0.64mm_HandSolder
R6, R7, R52: 100k; R_0402_1005Metric_Pad0.72x0.64mm_HandSolder
R8, R9, R21, R31, R32, R33, R34: 470; R_0402_1005Metric_Pad0.72x0.64mm_HandSolder
R14: 220; R_0402_1005Metric_Pad0.72x0.64mm_HandSolder
R20, R50, R51, R54: 4.7k; R_0402_1005Metric_Pad0.72x0.64mm_HandSolder
R29, R30, R35, R36, R53: NC; R_0402_1005Metric_Pad0.72x0.64mm_HandSolder
R61: 100; R_0402_1005Metric_Pad0.72x0.64mm_HandSolder
R162, R163, R165, R166, R167: NC; R_1206_3216Metric_Pad1.30x1.75mm_HandSolder
R164: 110R; R_1206_3216Metric_Pad1.30x1.75mm_HandSolder
SW1, SW2, SW3, SW4, SW5, SW6, SW7, SW8: SW_MEC_5E; SOIC4_TL3301SPF160RGTAPE_EWI
U3: STM32F103CBT6; LQFP-48_7x7mm_P0.5mm
U5: LSM6DS3TR-C; QFN_S3TR-C_STM
U6: IRM-H638T/TR2; IRM-H638T
Y1: TAXM8M4RFDCET2T; Oscillator_SMD_Abracon_ASE-4Pin_3.2x2.5mm

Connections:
/LED Matrix/A0: U3.39 (PB3); also elsewhere on the board
/LED Matrix/A1: U3.41 (PB5); also elsewhere on the board
/LED Matrix/A2: U3.45 (PB8); also elsewhere on the board
/LED Matrix/A3: U3.46 (PB9); also elsewhere on the board
/LED Matrix/DEC_EN: U3.40 (PB4); also elsewhere on the board
/MCU/BOOT0: R20.2, U3.44 (BOOT0)
/MCU/BTN_A: SW1.3 (K), SW1.4 (A), U3.38 (PA15)
/MCU/BTN_B: SW2.3 (K), SW2.4 (A), U3.14 (PA4)
/MCU/BTN_C: SW3.3 (K), SW3.4 (A), U3.15 (PA5)
/MCU/BTN_D: SW4.3 (K), SW4.4 (A), U3.16 (PA6)
/MCU/BTN_E: SW5.3 (K), SW5.4 (A), U3.17 (PA7)
/MCU/BTN_F: SW6.3 (K), SW6.4 (A), U3.29 (PA8)
/MCU/BTN_G: SW7.3 (K), SW7.4 (A), U3.30 (PA9)
/MCU/BTN_H: SW8.3 (K), SW8.4 (A), U3.31 (PA10)
/MCU/CA: U3.28 (PB15); also elsewhere on the board
/MCU/CB: U3.27 (PB14); also elsewhere on the board
/MCU/CC: U3.26 (PB13); also elsewhere on the board
/MCU/CD: U3.25 (PB12); also elsewhere on the board
/MCU/CE: U3.22 (PB11); also elsewhere on the board
/MCU/CF: U3.21 (PB10); also elsewhere on the board
/MCU/CG: U3.20 (PB2); also elsewhere on the board
/MCU/CH: U3.19 (PB1); also elsewhere on the board
/MCU/I2C1_SCL: R51.1, U3.42 (PB6), U5.13 (SCL)
/MCU/I2C1_SDA: R50.1, U3.43 (PB7), U5.14 (SDA)
/MCU/IRDRV: R14.1, U3.18 (PB0)
/MCU/IRDRV_G: Q9.1 (G), R14.2
/MCU/IRD_M1: D160.1 (K), D161.1 (K), R31.2, R32.2, R33.2, R34.2, R35.2, R36.2
/MCU/IRD_M2: D3.2 (A), R29.2
/MCU/IRD_M3: D162.1 (K), R162.2
/MCU/IRD_M4: D163.1 (K), R163.2
/MCU/IRD_M5: D164.1 (K), R164.2
/MCU/IRD_M6: D165.1 (K), R165.2
/MCU/IRD_M7: D166.1 (K), R166.2
/MCU/IRD_M8: D167.1 (K), R167.2
/MCU/IRD_N: D3.1 (K), D160.2 (A), D161.2 (A), D162.2 (A), D163.2 (A), D164.2 (A), D165.2 (A), D166.2 (A), D167.2 (A), Q9.3 (D)
/MCU/IRRX: U3.10 (PA0), U6.3 (OUTPUT)
/MCU/LSM6_PWR_CTRL: R52.2, R54.2, U3.4 (PC15)
/MCU/LSM6_PWR_GATE: Q50.1 (G), R54.1
/MCU/LSM6_VCC: C50.1, C51.1, Q50.3 (D), R50.2, R51.2, R53.1, U5.5 (VDDIO), U5.8 (VDD), U5.12 (CS)
/MCU/NOISE_IN: R4.2, R11.1, U3.11 (PA1)
/MCU/OSC_IN: C38.1, U3.5 (PD0), Y1.3 (OUT)
/MCU/OSC_OUT: R21.1, U3.6 (PD1)
/MCU/OSC_OUT_R: C37.1, R21.2, Y1.1 (EN)
/MCU/PA2: R8.2, U3.12 (PA2)
/MCU/PA3: R9.2, U3.13 (PA3)
/MCU/PA11: U3.32 (PA11); also elsewhere on the board
/MCU/PA12: U3.33 (PA12); also elsewhere on the board
/MCU/PA13: J3.3, U3.34 (PA13)
/MCU/PA14: J3.2, U3.37 (PA14)
/MCU/USB_DET: U3.3 (PC14); also elsewhere on the board
GND: C30.2, C31.2, C32.2, C33.2, C34.2, C37.2, C38.2, C50.2, C51.2, C60.2, C92.2, J3.1, J4.1, J5.3, J7.2, Q9.2 (S), R6.2, R7.2, R11.2, R20.1, R52.1, SW1.1, SW1.2, SW2.1, SW2.2, SW3.1, SW3.2, SW4.1, SW4.2, SW5.1, SW5.2, SW6.1, SW6.2, SW7.1, SW7.2, SW8.1, SW8.2, U3.8 (VSSA), U3.23 (VSS), U3.35 (VSS), U3.47 (VSS), U5.1 (SDO/SA0), U5.2 (SDx), U5.3 (SCx), U5.6 (GND), U5.7 (GND), U6.1 (GND), U6.2 (GND), Y1.2 (GND); also elsewhere on the board
unnamed: J4.2, R6.1, R8.1
unnamed: J5.2, R7.1, R9.1
unnamed: C34.1, R30.2, U3.7 (NRST)
unnamed: C60.1, R61.1, U6.4 (VCC)
VCC: C30.1, C31.1, C32.1, C33.1, C92.1, J3.4, J7.1, Q50.2 (S), R4.1, R29.1, R30.1, R31.1, R32.1, R33.1, R34.1, R35.1, R36.1, R53.2, R61.2, R162.1, R163.1, R164.1, R165.1, R166.1, R167.1, U3.9 (VDDA), U3.24 (VDD), U3.36 (VDD), U3.48 (VDD); also elsewhere on the board

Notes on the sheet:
For:Pin48
There's an internal pull up in STM32, so this may not be needed.
4:3V3 3:SWDIO 2:SWDCLK 1:GND
For:Pin24
For:Pin8
For:Pin9
USB_DET MUST only be connected to GPIO that allows for +5mA injection
For:Pin5
R11=R4, 8 to 10M Ohm
For:Pin36
For IR

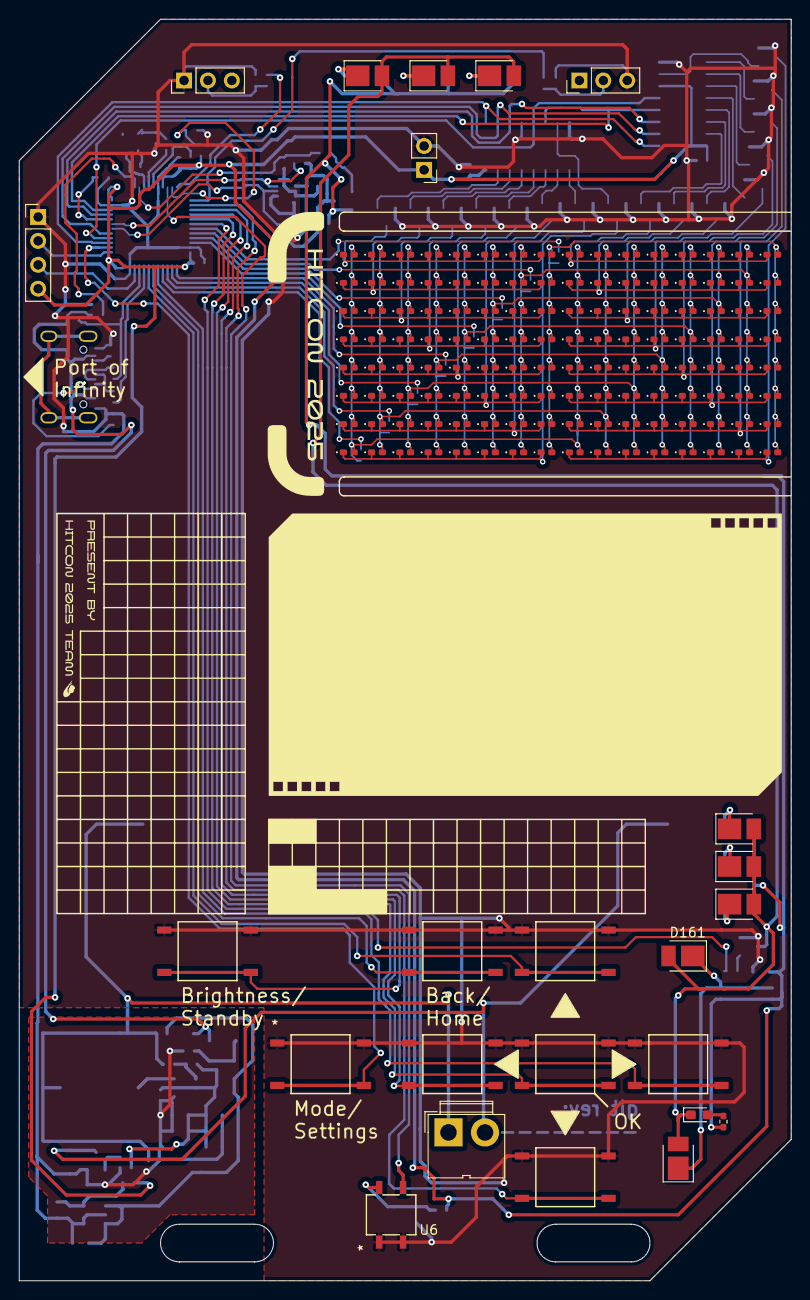
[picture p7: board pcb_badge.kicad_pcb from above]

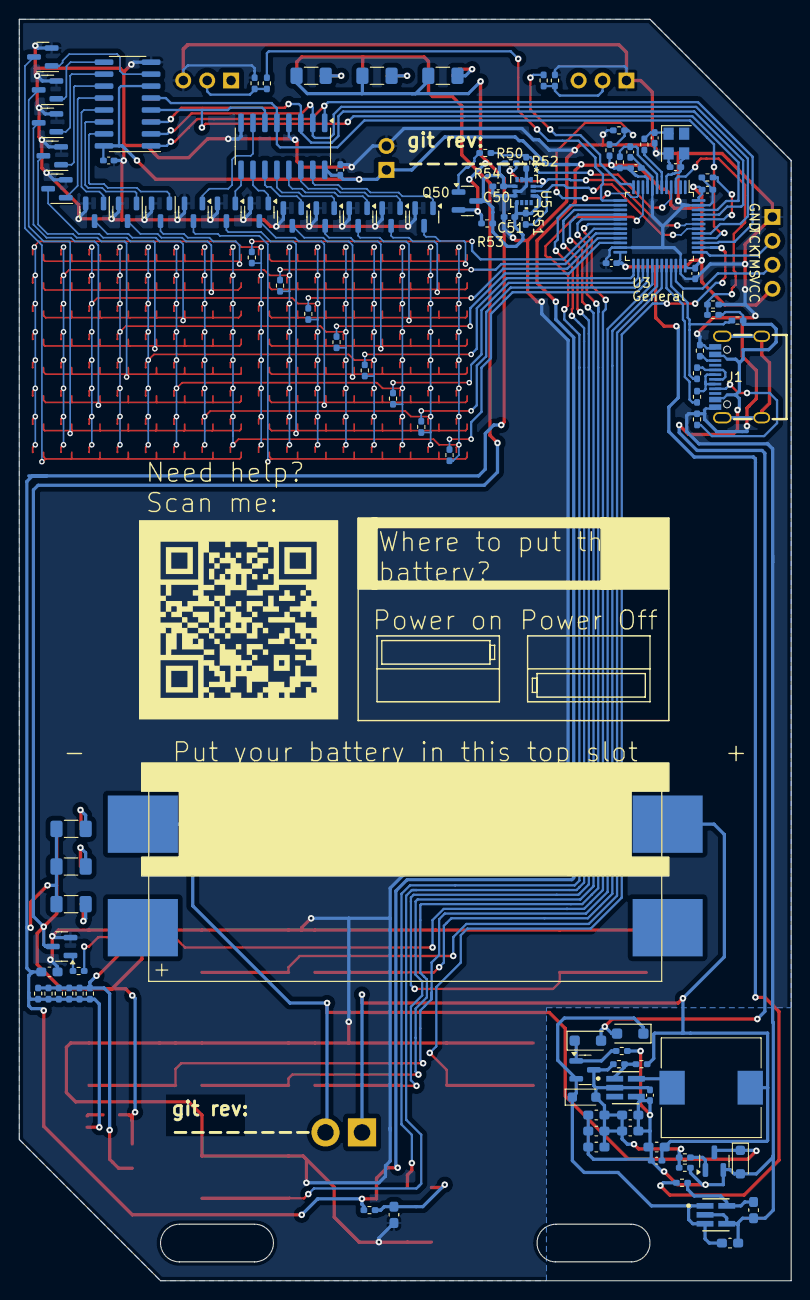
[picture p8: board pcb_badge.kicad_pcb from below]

Board: 2 copper layers, 82.0 x 134.0 mm, 258 parts (106 on the bottom side), 110 nets.

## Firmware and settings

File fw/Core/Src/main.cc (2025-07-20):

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
/* Includes ------------------------------------------------------------------*/
#include "main.h"
#include "adc.h"
#include "crc.h"
#include "dma.h"
#include "tim.h"
#include "usart.h"
#include "usb_device.h"
#include "gpio.h"

/* USER CODE BEGIN Includes */
#include <Hitcon.h>
#include "i2c.h"

/* USER CODE END Includes */


void SystemClock_Config(void);
/**
  * @brief  The application entry point.
  * @retval int
  */
int main(void)
{

  /* MCU Configuration--------------------------------------------------------*/

  /* Reset of all peripherals, Initializes the Flash interface and the Systick. */
  HAL_Init();

  /* Configure the system clock */
  SystemClock_Config();

  /* Initialize all configured peripherals */
  MX_GPIO_Init();
  MX_DMA_Init();
  MX_USART2_UART_Init();
  MX_TIM1_Init();
  MX_TIM3_Init();
  MX_TIM2_Init();
  MX_TIM4_Init();
  MX_ADC1_Init();
  MX_CRC_Init();
  MX_USB_DEVICE_Init();
  /* USER CODE BEGIN 2 */
#ifndef V1_1
  MX_I2C1_Init();
#endif
  hitcon_run();

  /* USER CODE END 2 */

  /* Infinite loop */
  /* USER CODE BEGIN WHILE */
  while (1) {
    /* USER CODE END WHILE */

    /* USER CODE BEGIN 3 */
  }
  /* USER CODE END 3 */
}

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


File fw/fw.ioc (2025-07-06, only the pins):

Mcu.UserName=STM32F103CBTx
PA0-WKUP.GPIO_Label=IrRx
PA0-WKUP.Signal=GPIO_Input
PA1.Signal=ADCx_IN1
PA10.GPIO_Label=BtnH
PA10.Signal=GPIO_Input
PA11.GPIO_Label=UsbDm
PA11.Signal=USB_DM
PA12.GPIO_Label=UsbDp
PA12.Signal=USB_DP
PA13.Signal=SYS_JTMS-SWDIO
PA14.Signal=SYS_JTCK-SWCLK
PA15.GPIO_Label=BtnA
PA15.Signal=GPIO_Input
PA2.Signal=USART2_TX
PA3.Signal=USART2_RX
PA4.GPIO_Label=BtnB
PA4.Signal=GPIO_Input
PA5.GPIO_Label=BtnC
PA5.Signal=GPIO_Input
PA6.GPIO_Label=BtnD
PA6.Signal=GPIO_Input
PA7.GPIO_Label=BtnE
PA7.Signal=GPIO_Input
PA8.GPIO_Label=BtnF
PA8.Signal=GPIO_Input
PA9.GPIO_Label=BtnG
PA9.Signal=GPIO_Input
PB0.GPIO_Label=IrTx
PB0.Signal=S_TIM3_CH3
PB1.GPIO_Label=LedCh
PB1.Signal=GPIO_Output
PB10.GPIO_Label=LedCf
PB10.Signal=GPIO_Output
PB11.GPIO_Label=LedCe
PB11.Signal=GPIO_Output
PB12.GPIO_Label=LedCd
PB12.Signal=GPIO_Output
PB13.GPIO_Label=LedCc
PB13.Signal=GPIO_Output
PB14.GPIO_Label=LedCb
PB14.Signal=GPIO_Output
PB15.GPIO_Label=LedCa
PB15.Signal=GPIO_Output
PB2.GPIO_Label=LedCg
PB2.Signal=GPIO_Output
PB3.GPIO_Label=LedA0
PB3.Signal=GPIO_Output
PB4.GPIO_Label=LedA1
PB4.Signal=GPIO_Output
PB5.GPIO_Label=DEC_EN
PB5.Signal=GPIO_Output
PB6.Signal=I2C1_SCL
PB7.Signal=I2C1_SDA
PB8.GPIO_Label=LedA2
PB8.Signal=GPIO_Output
PB9.GPIO_Label=LedA3
PB9.Signal=GPIO_Output
PC15-OSC32_OUT.GPIO_Label=IMU_INT1
PC15-OSC32_OUT.Signal=GPXTI15
PD0-OSC_IN.Signal=RCC_OSC_IN
PD1-OSC_OUT.Signal=RCC_OSC_OUT

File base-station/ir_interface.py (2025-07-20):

"""
USB Serial Commands:

Necessary Fields:
Preamble - 8 bytes. 0xD5 0x55 0x55 0x55 0x55 0x55 0x55 0x55

PacketType - 1 byte
    base station to badge (to ir):
        * 0x01 for QueueTxBufferRequest
        * 0x81 for QueueTxBufferResponse
        * 0x02 for RetrieveRxBufferRequest 
        * 0x82 for RetrieveRxBufferResponse
        * 0x03 for GetStatusRequest
        * 0x83 for GetStatusResponse
    
    base station to badge (to cross board, use trigger_send_packet(..., to_cross_board=True)):
        * 0x11 for QueueTxBufferRequest
        * 0x91 for QueueTxBufferResponse
        ... (other cross board commands)

    base station to badge (else, print on badge, use trigger_send_packet(..., print_on_badge=True)):
        * 0x07 for PrintOnBadgeRequest (No response)

    badge to base station (from ir):
        * 0x04 for PushTxBufferRequest
        * 0x84 for PushTxBufferResponse
        * 0x05 for PopRxBufferRequest
        * 0x85 for PopRxBufferResponse
        * 0x06 for SendStatusRequest
        * 0x86 for SendStatusResponse

    badge to base station (from cross board):
        * 0x14 for PushTxBufferRequest
        * 0x94 for PushTxBufferResponse
        ... (other cross board commands)

PacketSequence - 1 byte. A random byte to denote which response maps to which request.
    The response should have the same packet sequence as the request.

PacketSize - 1 byte.

Optional Fields:

Payload - x bytes, if PacketSize not 0x00

Payload content of each packet type:

QueueTxBufferRequest: (Computer to Badge)
x bytes - The entire buffer data to queue for transmit.

QueueTxBufferResponse: (Badge to Computer)
1 byte - 0x01 for buffer full, 0x02 for success.

RetrieveRxBufferRequest: (Computer to Badge)
None

RetrieveRxBufferResponse: (Badge to Computer)
x bytes for the entire buffer received.

GetStatusRequest: (Computer to Badge)
None

GetStatusResponse: (Badge to Computer)
1 byte - 0x01 for failure, 0x02 for success.
1 byte - Status:
            * 0x01: Set for not ready to receive, all received buffers has been populated with received packet.
            * 0x02: Set for ready to receive, there are empty received buffers exist on badge.


PushTxBufferRequest: (Badge to Computer) (for transfer badge status to allow QueueTxBufferRequest to be sent)
None

PushTxBufferResponse: (Computer to Badge)
x bytes - The entire buffer data to queue for transmit.

PopRxBufferRequest: (Badge to Computer)
x bytes - The entire buffer data to queue for transmit.

PopRxBufferResponse: (Computer to Badge)
1 byte - 0x01 for failure, 0x02 for success.

SendStatusRequest: (Badge to Computer)
1 byte - The status, same as above.

SendStatusResponse: (Computer to Badge)
None

"""

import serial
import enum
from config import Config
import asyncio
import time
from dataclasses import dataclass
from typing import Optional, List
import logging
logging.basicConfig(level=logging.DEBUG)
logger = logging.getLogger(__name__)

# Information prefixes in PacketType.
class PT_INFO(enum.Enum):
    CROSS_BOARD = 16 # Cross board command prefix = 0x10
    # Add more information prefixes if needed in the future.
    
    @staticmethod
    def add_infos(packet_type: bytes, infos: list) -> bytes:
        packet_type = int.from_bytes(packet_type, byteorder='big')

        for info in infos:
            packet_type = packet_type | info.value

        return packet_type.to_bytes(1, byteorder='big')
    

    # return bools indicating whether the info is in the packet_type.
    @staticmethod
    def is_infos_in(packet_type: bytes, infos) -> bool | list[bool]:
        packet_type = int.from_bytes(packet_type, byteorder='big')

        if type(infos) == PT_INFO:
            return (packet_type & infos.value) != 0
        
        return [((packet_type & info.value) != 0) for info in infos]

    # return list of PT_INFO, each PT_INFO indicates whether the info is in the packet_type.
    @staticmethod
    def get_all_info(packet_type: bytes) -> list:
        b_array = PT_INFO.is_infos_in(packet_type, list(PT_INFO))
        return [info for info, present in zip(list(PT_INFO), b_array) if present]

    @staticmethod
    def remove_infos(packet_type: bytes, infos: list) -> bytes:
        packet_type = int.from_bytes(packet_type, byteorder='big')

        for info in infos:
            packet_type = packet_type & ~(info.value)

        return packet_type.to_bytes(1, byteorder='big')

    
    @staticmethod
    def remove_all_info(packet_type: bytes) -> bytes:
        return PT_INFO.remove_infos(packet_type, list(PT_INFO))
    
    # return int representing sum of all info value in the input bytes.
    @staticmethod
    def get_info_value(packet_type: bytes) -> int:
        ori_pt = int.from_bytes(PT_INFO.remove_all_info(packet_type), byteorder='big')
        return ori_pt ^ int.from_bytes(packet_type, byteorder='big')

    @staticmethod
    def info_transfer(from_pt: bytes, to_pt: bytes) -> bytes:
        result = PT_INFO.get_info_value(from_pt) | int.from_bytes(to_pt, byteorder='big')
        return result.to_bytes(1, byteorder='big')
    

# PacketType without prefix.
class PT(enum.Enum):
    
    QTQ = b'\x01' # QueueTxBufferRequest
    QTR = b'\x81' # QueueTxBufferResponse
    RRQ = b'\x02' # RetrieveRxBufferRequest
    RRR = b'\x82' # RetrieveRxBufferResponse
    GSQ = b'\x03' # GetStatusRequest
    GSR = b'\x83' # GetStatusResponse
    PTQ = b'\x04' # PushTxBufferRequest
    PTR = b'\x84' # PushTxBufferResponse
    PRQ = b'\x05' # PopRxBufferRequest
    PRR = b'\x85' # PopRxBufferResponse
    SSQ = b'\x06' # SendStatusRequest
    SSR = b'\x86' # SendStatusResponse
    PBR = b'\x07' # PrintOnBadgeRequest

    def get_response(self):
        # Get the response packet type for the request packet type.
        request_response_map = {
            PT.QTQ: PT.QTR,
            PT.QTR: PT.QTR,
            PT.RRQ: PT.RRR,
            PT.RRR: PT.RRR,
            PT.GSQ: PT.GSR,
            PT.GSR: PT.GSR,
            PT.PTQ: PT.PTR,
            PT.PTR: PT.PTR,
            PT.PRQ: PT.PRR,
            PT.PRR: PT.PRR,
            PT.SSQ: PT.SSR,
            PT.SSR: PT.SSR,
            PT.PBR: PT.PBR
        }

        return request_response_map.get(self)

    def get_type_name(self) -> str:
        type_name_map = {
            PT.QTQ: "QueueTxBufferRequest",
            PT.QTR: "QueueTxBufferResponse",
            PT.RRQ: "RetrieveRxBufferRequest",
            PT.RRR: "RetrieveRxBufferResponse",
            PT.GSQ: "GetStatusRequest",
            PT.GSR: "GetStatusResponse",
            PT.PTQ: "PushTxBufferRequest",
            PT.PTR: "PushTxBufferResponse",
            PT.PRQ: "PopRxBufferRequest",
            PT.PRR: "PopRxBufferResponse",
            PT.SSQ: "SendStatusRequest",
            PT.SSR: "SendStatusResponse",
            PT.PBR: "PrintOnBadgeRequest"
        }

        return type_name_map.get(self)
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

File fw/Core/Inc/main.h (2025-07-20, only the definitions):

#define IMU_INT1_Pin GPIO_PIN_15
#define IMU_INT1_GPIO_Port GPIOC
#define IMU_INT1_EXTI_IRQn EXTI15_10_IRQn
#define IrRx_Pin GPIO_PIN_0
#define IrRx_GPIO_Port GPIOA
#define BtnB_Pin GPIO_PIN_4
#define BtnB_GPIO_Port GPIOA
#define BtnC_Pin GPIO_PIN_5
#define BtnC_GPIO_Port GPIOA
#define BtnD_Pin GPIO_PIN_6
#define BtnD_GPIO_Port GPIOA
#define BtnE_Pin GPIO_PIN_7
#define BtnE_GPIO_Port GPIOA
#define IrTx_Pin GPIO_PIN_0
#define IrTx_GPIO_Port GPIOB
#define LedCh_Pin GPIO_PIN_1
#define LedCh_GPIO_Port GPIOB
#define LedCg_Pin GPIO_PIN_2
#define LedCg_GPIO_Port GPIOB
#define LedCf_Pin GPIO_PIN_10
#define LedCf_GPIO_Port GPIOB
#define LedCe_Pin GPIO_PIN_11
#define LedCe_GPIO_Port GPIOB
#define LedCd_Pin GPIO_PIN_12
#define LedCd_GPIO_Port GPIOB
#define LedCc_Pin GPIO_PIN_13
#define LedCc_GPIO_Port GPIOB
#define LedCb_Pin GPIO_PIN_14
#define LedCb_GPIO_Port GPIOB
#define LedCa_Pin GPIO_PIN_15
#define LedCa_GPIO_Port GPIOB
#define BtnF_Pin GPIO_PIN_8
#define BtnF_GPIO_Port GPIOA
#define BtnG_Pin GPIO_PIN_9
#define BtnG_GPIO_Port GPIOA
#define BtnH_Pin GPIO_PIN_10
#define BtnH_GPIO_Port GPIOA
#define UsbDm_Pin GPIO_PIN_11
#define UsbDm_GPIO_Port GPIOA
#define UsbDp_Pin GPIO_PIN_12
#define UsbDp_GPIO_Port GPIOA
#define BtnA_Pin GPIO_PIN_15
#define BtnA_GPIO_Port GPIOA
#define LedA0_Pin GPIO_PIN_3
#define LedA0_GPIO_Port GPIOB
#define LedA1_Pin GPIO_PIN_4
#define LedA1_GPIO_Port GPIOB
#define DEC_EN_Pin GPIO_PIN_5
#define DEC_EN_GPIO_Port GPIOB
#define LedA2_Pin GPIO_PIN_8
#define LedA2_GPIO_Port GPIOB
#define LedA3_Pin GPIO_PIN_9
#define LedA3_GPIO_Port GPIOB
#define DEC_EN_GPIO_Port GPIOB
#define LedA0_Pin GPIO_PIN_6
#define LedA1_Pin GPIO_PIN_7
#define DEC_EN_Pin GPIO_PIN_5
#define LedA0_Pin GPIO_PIN_3
#define LedA1_Pin GPIO_PIN_4
#define DEC_EN_Pin GPIO_PIN_5
#define LedA0_Pin GPIO_PIN_3
#define LedA1_Pin GPIO_PIN_5
#define DEC_EN_Pin GPIO_PIN_4

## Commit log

2025-03-16 add accelerometer
    1. change LedA1, A0 pin connection
    2. add I2C1, U5 LSM6DS3TR-C
    3. disconnect USB_DET
    [LED Matrix.kicad_sch, LED Matrix2.kicad_sch, MCU.kicad_sch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]
2025-04-13 Implement new board graphics design
    [pcb_badge.kicad_pcb]
2025-04-20 Expand PCB Size
    Expand PCB Size to compensate cross-board header position
    [pcb_badge.kicad_pcb]
2025-04-20 pcb: Zone fill and pass DRC check
    [pcb_badge.kicad_pcb]
2025-04-20 pcb: Connect accelerometer INT1
    [MCU.kicad_sch, pcb_badge.kicad_pcb]
2025-05-03 update: fix tx and acknowledgement
    [packet_processor.py]
2025-05-03 fix: parse username into int
    [packet_processor.py]
2025-06-07 fix(backend): rx packet saving
    [packet_processor.py]
2025-06-07 fix(backend): event handler registration
    [packet_processor.py]
2025-06-07 fix: read correct hash value from ack packet
    [packet_processor.py]
2025-06-07 fix: remove int timestamp passed to IrPacketObject
    [packet_processor.py]
2025-06-07 base-station: Fix base-station to work end to end
    [backend_interface.py, main.py, packet_processor.py]
2025-06-22 Swap DEC_A1 and DEC_EN
    fix TIM3_CH2 and I2C1 conflict
    [MCU.kicad_sch, pcb_badge.kicad_pcb]
2025-06-22 pcb: Add USBDET back to STM32
    [MCU.kicad_sch, Power.kicad_sch, pcb_badge.kicad_pcb]
2025-06-22 fix: missing import for UnsignedPacketError
    [packet_processor.py]
2025-06-22 fix: calculate hash for non-signed packets
    [packet_processor.py]
2025-06-22 fix: ack with packet id
    [packet_processor.py]
2025-06-22 fix: push rx to packets
    [packet_processor.py]
2025-06-25 Update pcb_badge.kicad_sch
    Add resistor value comments for different LED colors
    [pcb_badge.kicad_sch]
2025-06-25 base-station: Fix integration issue on PubAnnounce with the backend
    [backend_interface.py, packet_processor.py]
2025-06-26 Add framework for Tama App
2025-06-26 Create basic framework for Tama App
2025-06-26 doc: update UI switching logic design
2025-06-26 update fw.ioc and display for accelerometer
    - add i2c1
    - update DisplayService
    - add EXTI IMU_INT1
2025-06-26 fix: assign PB5 as GPIO_Output
    due to TIM3_CH2 conflict with I2C1
    [fw.ioc, main.h, tim.c]
2025-06-26 Enable I2C1 interrupt mode
2025-06-26 Add IMU service and logic
    Implement initialization and self test
    TODO: get step count and INT1 EXTI
2025-06-26 pcb: Update Alternative Parts due to inventory
    U1 C2867699 -> C19631758
    J4 C2894945 -> C5383096
    J5 C2897385 -> C2935993
    U4, U8 C5379113 -> C7432189
    R11, R4 C103174 -> C177265
    [MCU.kicad_sch, pcb_badge.kicad_pcb]
2025-06-26 pcb: Add notes on production with jlc
2025-06-26 Update QRCode to 2025 version
    [pcb_badge.kicad_pcb]
2025-06-27 pcb: Adjust production_notes on confirmation
2025-06-27 pcb: Adjust top marking by (x+0.1mm, y-2mm)
    [pcb_badge.kicad_pcb]
2025-06-27 pcb: Adjust silkscreens to fix DRC
    [pcb_badge.kicad_pcb]
2025-06-27 pcb: Update SW
    SW1-SW9 C255812 -> C7528752
    Rotation is also updated
    [rotations.csv]
2025-06-29 Change I2C1 to fast mode
2025-06-29 ImuLogic add get step function
2025-06-29 pcb: Revert Switches
    SW1-SW9 C7528752 -> C255812
    Because the footprint doesn't work.
2025-07-13 add Print On Badge packet type
2025-07-13 Tama: Add basic framework for xboard logic
2025-07-13 Add QTE framework
2025-07-18 base-station: Fix packet processor type issue
    [packet_processor.py]
2025-07-18 base-station: Add display of current score/progress
2025-07-19 pcb: Fix size of last_step in ImuLogic
    step count is 16 bit, using 8 bit step count may cause overflow earlier
    than expected.
2025-07-19 feat: the compress method of const icon and the decompress method in runtime (+5 squashed commits)
    Squashed commits:
    [063cea1] feat: compress method of original icon, component and frame
    [389c976] refactor: adjust num icon size and relative things, for future data compress
    [2d32b0a] feat: memory free management & dog/cat idle frame separation
    [1bd7987] feat: dog and cat idle with overview status
    [572652f] refactor: separate simulation part and common part
2025-07-19 feat: all components and examples converted to compressed version (+2 squashed commits)
    [64b6a0f] fix: compress width larger then 8 / doc: comment of calculation method
    [36438b2] refactor: change material name with clear tag
    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
2025-07-19 feat: add training/battle frame and anime (+3 squashed commits)
    [27bca71] refactor: update image stack usage
    [ad4b5ed] feat: screen of healing of cat and dog
    [9d05fd3] feat: add conditional compiling switch to separate simulation code and real env code
    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
2025-07-19 feat: training result icon and amine / refactor: blank frame (+3 squashed commits)
    [1ea7393] doc: update wireframe design
    [e943235] feat: feed confirm & feeding icon+anime
    [99b972f] feat: food / hp / level frame
    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
2025-07-19 feat: real dog and cat selection on the board
    * adjusted malloc and free to new and delete
2025-07-19 feat: hatching egg, warning and idle
    * notice:
    1. the feature to get the motion change is not finished yet
    2. the hatching is simulated by button click to adjust the state, need to delete someday
    * bug:
    1. freeze after a period of idle
2025-07-19 temporary hack to insert per-board private key
2025-07-20 base-station: Add missing display task
    [packet_processor.py]
2025-07-20 base-stn: Cleanup traceback in backend interface and increase timeout
2025-07-20 fw: Add debug app for accelerometer
2025-07-20 Update tower_game_mechanics.md
    20250720
    贊助商活動設計
    對戰分數機制調整
2025-07-20 pcb: Added markings on version V2.1br
    [pcb_badge.kicad_pcb]
2025-07-20 pcb: Generate production files for V2.1br
    [BOM-pcb_badge.csv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]
2025-07-20 pcb: Update parts for inventory issue
    R162, R163, R165, R166, R167 -> NC
    J5 C2935993 -> C2897385
    [MCU.kicad_sch, pcb_badge.kicad_pcb]
2025-07-20 pcb: Added markings on version V2.1cr
    [pcb_badge.kicad_pcb]
2025-07-20 pcb: Generate production files for V2.1cr
    [BOM-pcb_badge.csv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]
2025-07-20 pcb: Adjust text for port of infinity
    [pcb_badge.kicad_pcb]
2025-07-20 pcb: Added markings on version V2.1dr
    [pcb_badge.kicad_pcb]
2025-07-20 pcb: Generate production files for V2.1dr
    [pcb_badge-CuBottom.gbr, pcb_badge-CuTop.gbr, pcb_badge-EdgeCuts.gbr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]
2025-07-20 pcb: Reset git revision marking
    [pcb_badge.kicad_pcb]
2025-07-20 pcb: Add power switch for LSM6DS3
    [MCU.kicad_sch, pcb_badge.kicad_pcb]
2025-07-21 pcb: Add serial current limiting resistor to gate of PMOS for control of LSM6Ds3
    Also update some silkscreen fonts
    [MCU.kicad_sch, pcb_badge.kicad_pcb]
2025-07-25 refactor: reduce frame data copy

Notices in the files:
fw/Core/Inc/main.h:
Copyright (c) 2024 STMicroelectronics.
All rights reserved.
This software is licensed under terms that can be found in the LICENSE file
